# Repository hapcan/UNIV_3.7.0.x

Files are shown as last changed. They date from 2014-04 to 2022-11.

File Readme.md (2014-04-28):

UNIV 3.7.0.x
============

BlIND CONTROLLER - 3 channel for AC motors 230V 200VA for DIN rail

Device webpage: http://hapcan.com/devices/universal/univ_3/univ_3-7-0-x/

Hardware created in Eagle PCB Software http://www.cadsoftusa.com/

Firmware created in Microchip MPLAB http://www.microchip.com/mplabide/ in assembly language

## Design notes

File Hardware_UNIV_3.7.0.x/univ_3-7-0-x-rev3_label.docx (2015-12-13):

BLIND CONTROLLER

3 CHANNEL for AC MOTORS
UN = 230V AC | | SMAX = 200VA /channel
TYPE | UNIV 3.7.0.x
S/N | 00000678h
BUS BUS | hapcan.com

STEROWNIK ROLET

3 KANAŁOWY DLA SILNIKÓW AC
UN = 230V AC | | SMAX = 200VA /kanał
TYP | UNIV 3.7.0.x
S/N | 00000678h
BUS BUS | hapcan.com

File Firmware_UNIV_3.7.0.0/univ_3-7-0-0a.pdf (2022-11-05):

# BLIND CONTROLLER FIRMWARE

# UNIV 3.7.0.0

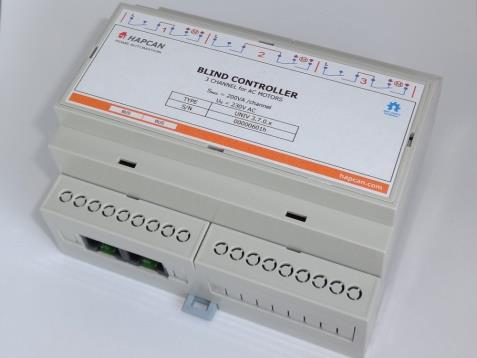
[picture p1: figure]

© 2014 hapcan.com | univ_3-7-0-0a.pdf - page 1 / 5

### 1. Features

- 3 channel blind controller firmware.
- 6 control instructions roletami (START, STOP, UP, DOWN, UP/STOP, DOWN/STOP) makes possible to drive blind with one two or three buttons.
- It estimates position of the blind by the running time.
- 3 timers (1 for each channel) 1s-24h for instruction execution delay.

### - 3 timers (1 for each channel) 1s-256s defining maximum motor running

time.

### - 3 blocking instructions - Allows defining up to 128 CAN messages which can indirectly control the module - Uptime counter - Health check monitor - Transmit (42 messages) and receive (42 messages) FIFO buffers

### 2. Compatibility

### - Firmware for UNIV 3.7.0.x module - Firmware can be uploaded into processor with bootloader version 3.1 or

compatible.

### 3. Firmware version

UNIV | 3 | . | 7 | . | 0 | . | 0

### firmware version application version (blind controller for AC motors) application type (blind controller) processor version universal processor

### 4. Communication Frames (messages)

### 4.1. Blind Controller Frame

The module sends message to the bus, when motors starts running or stops.

Table 1. BLIND CONTROLLER frame (0x307).
Frame type | Flags | Module | Group | D0 | D1 | D2 | D3 | D4 | D5 | D6 | D7
0x307 | 3 | 2 | 1 | 0 | Node Nr | Group Nr | 0xFF | 0xFF | CHANNEL | STATUS | MOVE | INSTR1 | INSTR2 | TIMER
0x307 | – universal module frame, blind controller application
3 | - | - not used flag, read as “0”
2 | - | - not used flag, read as “0”
1 | - | - not used flag, read as “0”
0 | RE | - response flag. Flag is equal “1” if node was requested. If flag is equal „0” it means that status of output has just changed.
Node Nr | - node number on the network
Group Nr | - group number of the node on the network
CHANNEL | - blind number
STATUS | - estimated blind status (0x00-0xFF): 0x00 – blind open, 0xFF – blind closed
MOVE | - defines movement: 0x00 – blind stopped, 0x01 – going down, 0x02 – going up
INSTR1 | - instruction that is waiting for execution, or 0xFF if none instruction
INSTR2 | - second byte of instruction that is waiting for execution, or 0xFF
TIMER | - delay value of waiting instruction, or 0x00 if none waiting

## UNIV 3.7.0.0

### 4.2. Status request

Status of module can be checked by sending from computer STATUS REQUEST frame (0x109) (Table 2).

Table 2. STATUS REQUEST frame (0x109).
Frame type | Flags | Module | Group | D0 | D1 | D2 | D3 | D4 | D5 | D6 | D7
0x109 | 0x0 | COMP ID1 | COMP ID2 | 0xXX | 0xXX | Node Nr | Group Nr | 0xXX | 0xXX | 0xXX | 0xXX
0x1090 | – STATUS REQUEST frame
COMP ID1 | - computer identifier (must be unique on the network)
COMP ID2 | - computer identifier (must be unique on the network)
Node Nr | - node number of requested module
Group Nr | - group number of requested module
0xXX | - inessential data

As response the module will send status frames (Table 3). Meaning of bytes is the same as in Table 1.

Table 3. Response to STATUS REQUEST.
Frame type | Flags | Module | Group | D0 | D1 | D2 | D3 | D4 | D5 | D6 | D7
0x307 | 0x1 | Node Nr | Group Nr | 0xFF | 0xFF | 0x01 | STATUS | MOVE | INSTR1 | 0x01 | TIMER1
Frame type | Flags | Module | Group | D0 | D1 | D2 | D3 | D4 | D5 | D6 | D7
0x307 | 0x1 | Node Nr | Group Nr | 0xFF | 0xFF | 0x02 | STATUS | MOVE | INSTR1 | 0x02 | TIMER2
Frame type | Flags | Module | Group | D0 | D1 | D2 | D3 | D4 | D5 | D6 | D7
0x307 | 0x1 | Node Nr | Group Nr | 0xFF | 0xFF | 0x03 | STATUS | MOVE | INSTR1 | 0x04 | TIMER3

### 4.3. Uptime request

Table 4. UPTIME REQUEST (0x113).
Frame type | Flags | Module | Group | D0 | D1 | D2 | D3 | D4 | D5 | D6 | D7
0x113 | 0x0 | COMP ID1 | COMP ID2 | 0xXX | 0xXX | Node Nr | Group Nr | 0xXX | 0xXX | 0xXX | 0xXX
0x1130 | – UPTIME REQUEST frame
COMP ID1 | - computer identifier (must be unique on the network)
COMP ID2 | - computer identifier (must be unique on the network)
Node Nr | - node number of requested module
Group Nr | - group number of requested module
0xXX | - inessential data

Table 5. Response to UPTIME REQUEST (0x113).
Frame type | Flags | Module | Group | D0 | D1 | D2 | D3 | D4 | D5 | D6 | D7
0x113 | 0x1 | Node Nr | Group Nr | 0xFF | 0xFF | 0xFF | 0xFF | UPTIME3 | UPTIME2 | UPTIME1 | UPTIME0
0x1131 | – Response to UPTIME REQUEST frame
Node Nr | - node number on the network
Group Nr | - group number of the node on the network
UPTIME | - (UPTIME3*256³+UPTIME2*256²+UPTIME1*256¹+UPTIME3*256⁰
) in seconds

### 4.4. Health check request

Table 6. HEALTH CHECK - STATUS REQUEST (0x115).
Frame type | Flags | Module | Group | D0 | D1 | D2 | D3 | D4 | D5 | D6 | D7
0x115 | 0x0 | COMP ID1 | COMP ID2 | 0x01 | 0xXX | Node Nr | Group Nr | 0xXX | 0xXX | 0xXX | 0xXX
0x1150 | – HEALTH CHECK REQUEST frame
COMP ID1 | - computer identifier (must be unique on the network)
COMP ID2 | - computer identifier (must be unique on the network)
0x01 | - status request
Node Nr | - node number of requested module
Group Nr | - group number of requested module
0xXX | - inessential data

As response the module will send two frames (Table 7).

Table 7. Response to HEALTH CHECK - STATUS REQUEST (0x115).
Frame type | Flags | Module | Group | D0 | D1 | D2 | D3 | D4 | D5 | D6 | D7
0x115 | 0x1 | Node Nr | Group Nr | 0x01 | RXCNT | TXCNT | RXCNTMX | TXCNTMX | CANINTCNT | RXERRCNT | TXERRCNT
0x1151 | – Response to HEALTH CHECK REQUEST frame
Node Nr | - node number on the network
Group Nr | - group number of the node on the network
0x01 | - frame 1 (current values)
RXCNT | - current level of receive FIFO buffer
TXCNT | - current level of transmit FIFO buffer
RXCNTMX | - maximum level of receive FIFO buffer since power up
TXCNTMX | - maximum level of transmit FIFO buffer since power up
CANINTCNT | - number of CAN interface restarts since power up
RXERRCNT | - current receive errors register
TXERRCNT | - current transmit errors register
Frame type | Flags | Module | Group | D0 | D1 | D2 | D3 | D4 | D5 | D6 | D7
0x115 | 0x1 | Node Nr | Group Nr | 0x02 | 0xFF | 0xFF | RXCNTMXE | TXCNTMXE | CANINTCNTE | RXERRCNTE | TXERRCNTE
0x1151 | – Response to HEALTH CHECK REQUEST frame
Node Nr | - node number on the network
Group Nr | - group number of the node on the network
0x02 | - frame 2 (maximum values saved in eeprom memory)
RXCNTMXE | - maximum ever level of receive FIFO buffer
TXCNTMXE | - maximum ever level of transmit FIFO buffer
CANINTCNTE | - maximum ever number of CAN interface restarts
RXERRCNTE | - maximum ever receive errors
TXERRCNTE | - maximum ever transmit errors

To clear maximum values saved in eeprom memory the frame shown in Table 8 must be sent. There is no response to this message.

Table 8. HEALTH CHECK - CLEAR REQUEST (0x115).
Frame type | Flags | Module | Group | D0 | D1 | D2 | D3 | D4 | D5 | D6 | D7
0x115 | 0x0 | COMP ID1 | COMP ID2 | 0x02 | 0xXX | Node Nr | Group Nr | 0xXX | 0xXX | 0xXX | 0xXX
0x1150 | – HEALTH CHECK REQUEST frame
COMP ID1 | - computer identifier (must be unique on the network)
COMP ID2 | - computer identifier (must be unique on the network)
0x02 | - clear request
Node Nr | - node number of requested module
Group Nr | - group number of requested module
0xXX | - inessential data

### 5. Module control

The module can be controlled directly from PC, or indirectly by other modules. In both situation all instructions in the table below can be used. Blocking instructions can’t be used in direct control.

### 5.1. Control instruction

The Table 9 shows instructions, which can be executed by the module.

### Table 9. Module control instructions

Instruction | Instruction Codding | Note | Control
INSTR1 | INSTR2 | INSTR3 | INSTR4 | INSTR5 | INSTR6 | INSTR7 | INSTR8
STOP | 0x00 | CHANNEL | TIMER | 0xXX | 0xXX | 0xXX | 0xXX | 0xXX | It stops chosen blinds. Executing of the next instruction will be possible only after 1 second. | √ | √
UP/STOP | 0x01 | CHANNEL | TIMER | 0xXX | 0xXX | 0xXX | 0xXX | 0xXX | It runs blind up, if it was stopped. It stops blind, if it was running.
DOWN/STOP | 0x02 | CHANNEL | TIMER | 0xXX | 0xXX | 0xXX | 0xXX | 0xXX | It runs blind down, if it was stopped. It stops blind, if it was running.
UP | 0x03 | CHANNEL | TIMER | 0xXX | 0xXX | 0xXX | 0xXX | 0xXX | It runs blind up, if was stopped. It stops, and after 1s runs blind up, if was running down.
DOWN | 0x04 | CHANNEL | TIMER | 0xXX | 0xXX | 0xXX | 0xXX | 0xXX | It runs blind down, if was stopped. It stops, and after 1s runs blind down, if was running up.
START | 0x05 | CHANNEL | TIMER | 0xXX | 0xXX | 0xXX | 0xXX | 0xXX | It stops blind if was running. It runs blind opposite way to last running, if blind was stopped.

Direct

Indirect

0xXX – inessential data

CHANNEL | Note
0x01 | - <00000001> - only blind 1
0x02 | - <00000010> - only blind 2
0x03 | - <00000011> - blind 1 & 2
0x04 | - <00000100> - only blind 3
…
0x07 | - <00000111> - blind 1, 2, 3
bit <0> - blind 1
bit <1> - blind 2
bit <2> - blind 3
TIMER | Note
0x00 | - instruction will be executed immediately
0x01 | - instruction will be executed with 1s delay
…
0xFF | - instruction will be executed with 24h delay
ENABLE BOX | 0xDD | BoxX | BoxY | 0xXX | 0xXX | 0xXX | 0xXX | 0xXX | It enables chosen boxes – these boxes will be compared with next received message from the bus. | √
DISABLE BOX | 0xDE | BoxX | BoxY | 0xXX | 0xXX | 0xXX | 0xXX | 0xXX | It disables chosen boxes – these boxes will be passed when next message arrives from the bus. | √
TOGGLE BOX | 0xDF | BoxX | BoxY | 0xXX | 0xXX | 0xXX | 0xXX | 0xXX | It toggles boxes – enables when they are disabled and vice versa | √

0xXX – inessential data

BoxX | Note
0x00 | - from Box 1
0x01 | - from Box 2
…
0x7F | - from Box 128
BoxY | Note
0x00 | + 0 -(and not anyone else)
0x01 | + 1 -( and 1 following)
…
0x7F | +127 -( and 127 following)

### 5.2. Timer

Each relay has its own timer which can delay execution of the instruction. Delay can be chosen between 1s-24h set in TIMER register. Drawing below shows delay dependence of TIMER register.

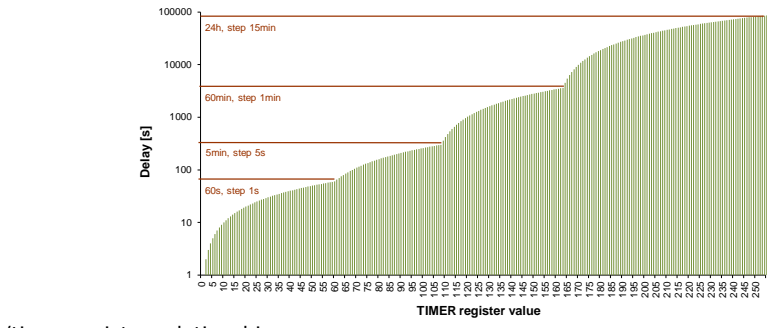
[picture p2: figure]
Delay [s]; TIMER register value; 60s, step 1s; 5min, step 5s; 60min, step 1min; 24h, step 15min

### Figure 1. Delay/timer register relationship

### 5.3. Direct control

It is possible to control module by sending DIRECT CONTROL message. The message contains instruction, which will be executed by the module. The module can be also controlled from HAPCAN Programmer.

Table 10. DIRECT CONTROL frame (0x10A).
Frame type | Flags | Module | Group | D0 | D1 | D2 | D3 | D4 | D5 | D6 | D7
0x10A | 0x0 | COMP ID1 | COMP ID2 | INSTR1 | INSTR2 | Node Nr | Group Nr | INSTR3 | INSTR4 | INSTR5 | INSTR6
0x10A | – DIRECT CONTROL frame
COMP ID1 | - computer identifier (must be unique on the network)
COMP ID2 | - computer identifier (must be unique on the network)
Node Nr | - node number of requested module
Group Nr | - group number of requested module
INSTR1-6 | - instruction to be executed (byte1)

### 5.4. Indirect control

Indirect control means that module will react to messages sent by other modules on the network. It depends on configuration programmed into the module boxes (memory cells).
This firmware has feature to set simple conditions of executing instruction. To do so, you can use blocking instruction (0xDD – 0xDF) shown in Table 9.

### 6. Configuration Parameters that can be configured with this firmware:

- Module identifier (module number and group number);
- Module description (16 chars);
- Blind names;
- Blind running times;
- Text notes;
- Linking device with other modules (indirect control of module). Configuration process can be done using HAPCAN Programmer.

### 6.1. Module identifier

Every module on the network must have unique identifier. The identifier is made of two bytes, module number (1 byte) and group number (1 byte). Identifier of the Ethernet Interface can be changed in HAPCAN Programmer in software settings.

### 6.2. Module description

Every module can have 16 char description, which makes easier for user (programmer) to distinguish nodes.

### 6.3. Relay Names

Each relay can be named with 32 chars.

### 6.4. Blind running time

For every channel (motor) the running time can be chosen. It is the time needed for complete closing of the blind from complete open position, or complete opening from complete shutting, whichever is longer. Basing on this time the module will estimate position of the blind.

6.5. Text notes.
Up to 1024 characters can be written into processor’s memory.

### 6.6. Linking devices

The module has 128 memory cells (boxes). Each box can contain information about message sent by other node, and instruction which will be executed when that message is received.

### 7. License

HAPCAN Home Automation Project firmware, Copyright (C) 2014 hapcan.com

This program is free firmware: you can redistribute it and/or modify it under the terms of the GNU General Public License as published by the Free Software Foundation, either version 3 of the License, or (at your option) any later version.

This firmware is distributed in the hope that it will be useful, but WITHOUT ANY WARRANTY; without even the implied warranty of MERCHANTABILITY or FITNESS FOR A PARTICULAR PURPOSE. See the GNU General Public License for more details.

You should have received a copy of the GNU General Public License along with this firmware. If not, see http://www.gnu.org/licenses/gpl-3.0.html.

### 8. Document version

File | Note | Date
univ_3-7-0-0a.pdf | Original version | April 2014

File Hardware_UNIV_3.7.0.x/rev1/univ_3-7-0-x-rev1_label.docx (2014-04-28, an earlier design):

BLIND CONTROLLER

3 CHANNEL for AC MOTORS

SMAX = 200VA /channel

UN = 230V AC
TYPE | UNIV 3.7.0.x
S/N | 00000601h
BUS BUS | hapcan.com

STEROWNIK ROLET

3 KANAŁOWY DLA SILNIKÓW AC

SMAX = 200VA /kanał

UN = 230V AC
TYP | UNIV 3.7.0.x
S/N | 00000601h
BUS BUS | hapcan.com

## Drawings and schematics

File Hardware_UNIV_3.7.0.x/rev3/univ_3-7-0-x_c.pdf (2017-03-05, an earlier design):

## BLIND CONTROLLER FOR AC MOTORS

# UNIV 3.7.0.x

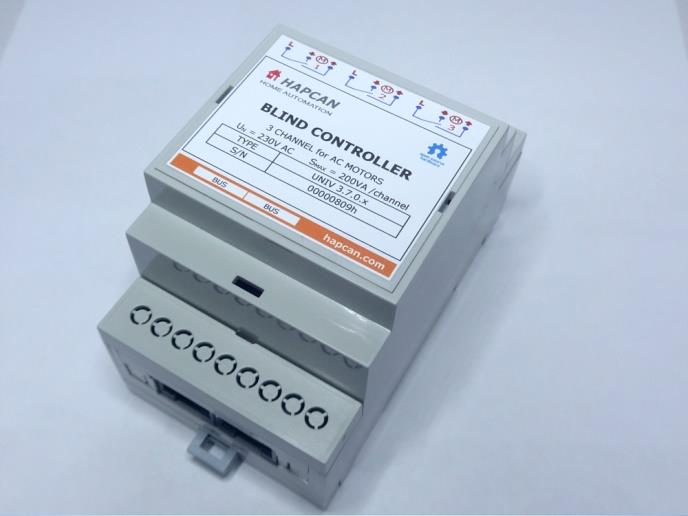
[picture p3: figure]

© 2015 hapcan.com | univ_3-7-0-x_c.pdf - page 1 / 6

### 1. Features

- 3 channel blind controller for blinds with AC motors 230V 200VA.
- The blind must have built-in limit switches and motor overload protection
- Motor running direction is defined by driven winding (forward or reverse)
- The module makes impossible to drive two motor windings at the same time.
- Motor nominal voltage 230V
- Maximum motor power 200VA
- Bus voltage 16-24V
- Maximum current consumption from the bus 83mA@16V
- For DIN rail mounting.
- Dimensions 90x58x53 mm (3 mod)
- Operating of module depends on firmware uploaded into it.
- Schematic and PCB design can be downloaded from hapcan.com site

### 2. Application version

UNIV | 3 | . | 7 | . | 0 | . | x
firmware version
application version (blind controller for AC motors) application type (blind controller)
processor version
universal processor

### 3. Technical data

Bus side
Parameter | Symbol | Value | Unit
Power supply voltage | US | 16-24 | V DC
Current consumption | IS | 8@16V 6@24V | mA
Maximum current consumption (when all relays are on – 3 blinds go up) | ISMAX | 83@16V 56@24V | mA
Bus connector type | 2x RJ45

Relay side
Parameter | Symbol | Value | Unit
Coil voltage | UCOIL | 12 | V DC
Coil resistance | RCOIL | 840 | Ω
Nominal contacts current | IN | 6 | A
Maximum inrush current | IINRUSH | 10 | A
Nominal motor voltage. | UN | 230 | V AC
Maximum load per channel. | SMAX | 200 | VA
Relay connector type | Terminal Blocks (solid wire 4mm² , stranded 2,5mm² )

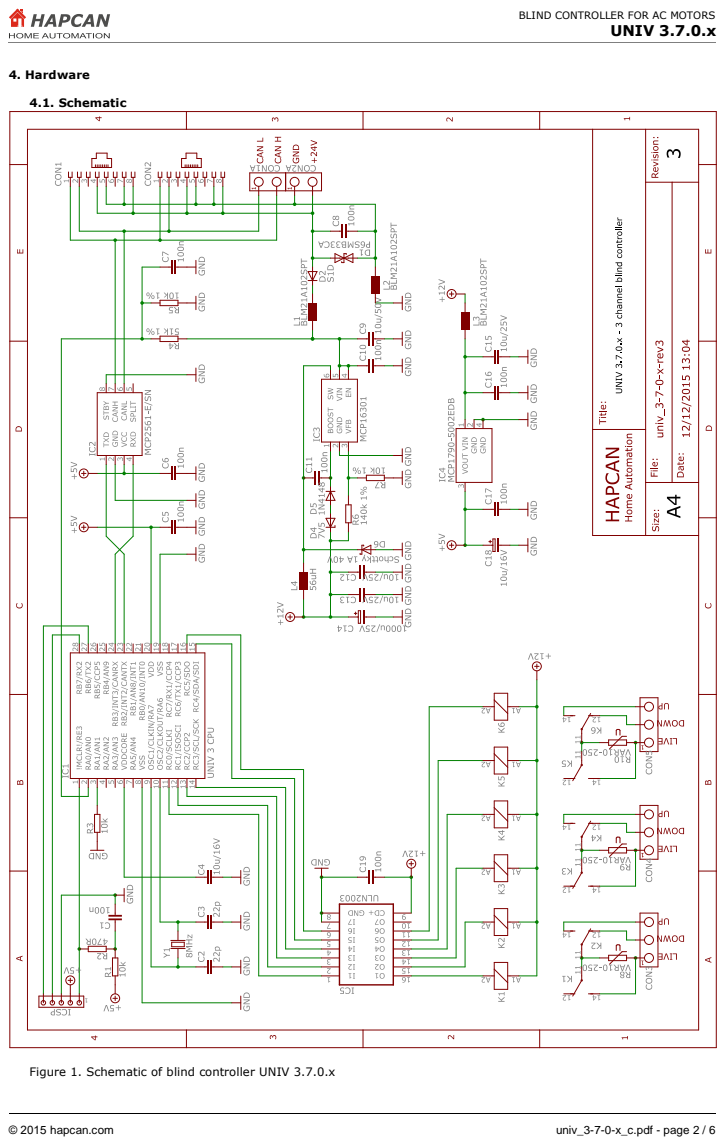
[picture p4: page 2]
4. Hardware; 4.1. Schematic

Figure 1. Schematic of blind controller UNIV 3.7.0.x

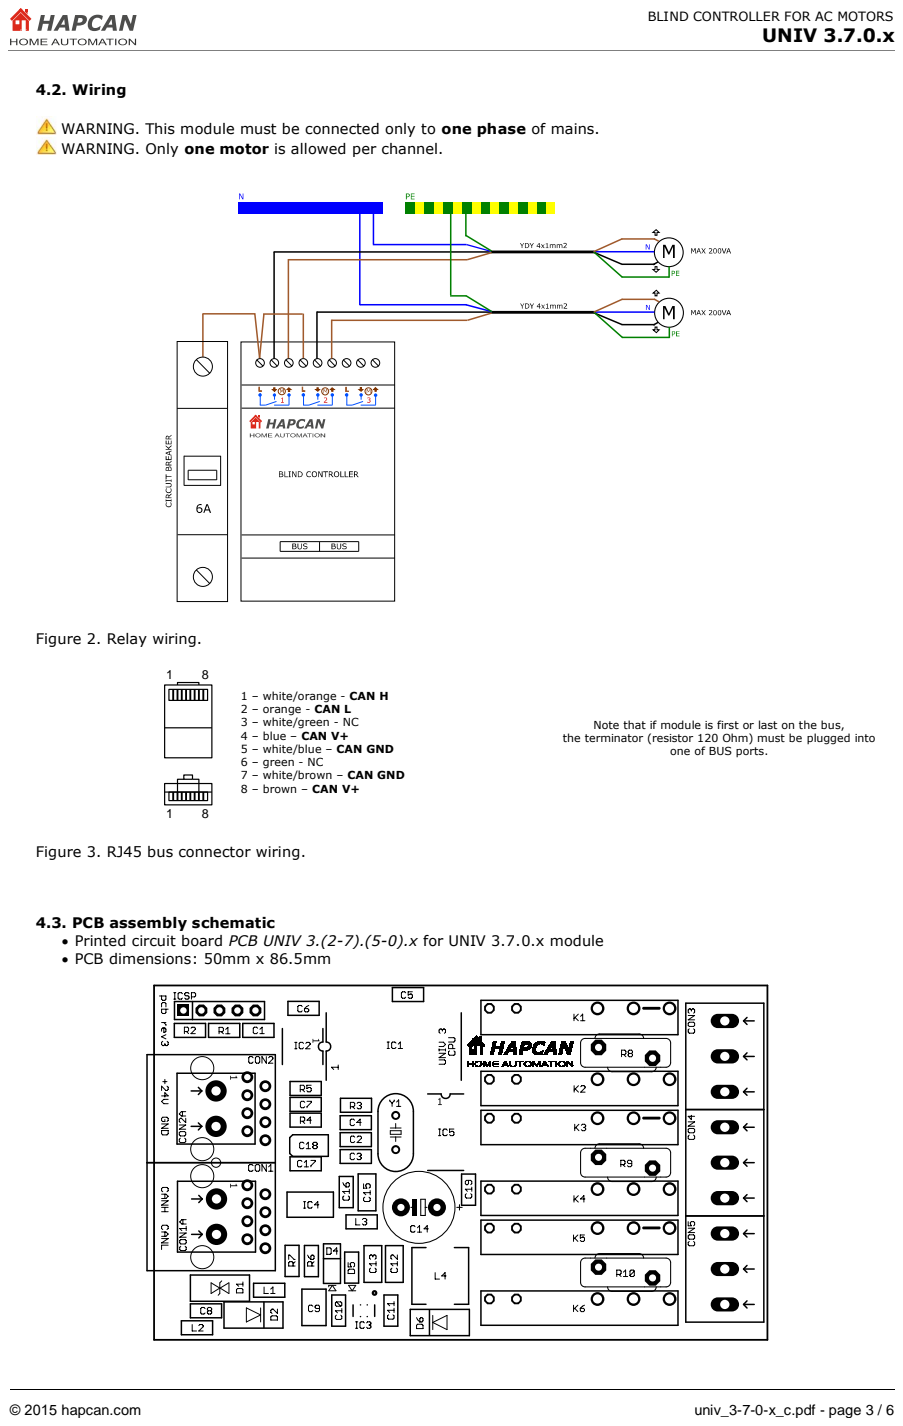
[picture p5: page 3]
4.2. Wiring

WARNING. This module must be connected only to one phase of mains.
WARNING. Only one motor is allowed per channel.

Figure 2. Relay wiring.

1 – white/orange - CAN H
2 – orange - CAN L
3 – white/green - NC
4 – blue – CAN V+
5 – white/blue – CAN GND
6 – green - NC
7 – white/brown – CAN GND
8 – brown – CAN V+

Note that if module is first or last on the bus,
the terminator (resistor 120 Ohm) must be plugged into

one of BUS ports.

Figure 3. RJ45 bus connector wiring.

4.3. PCB assembly schematic
• Printed circuit board PCB UNIV 3.(2-7).(5-0).x for UNIV 3.7.0.x module
• PCB dimensions: 50mm x 86.5mm

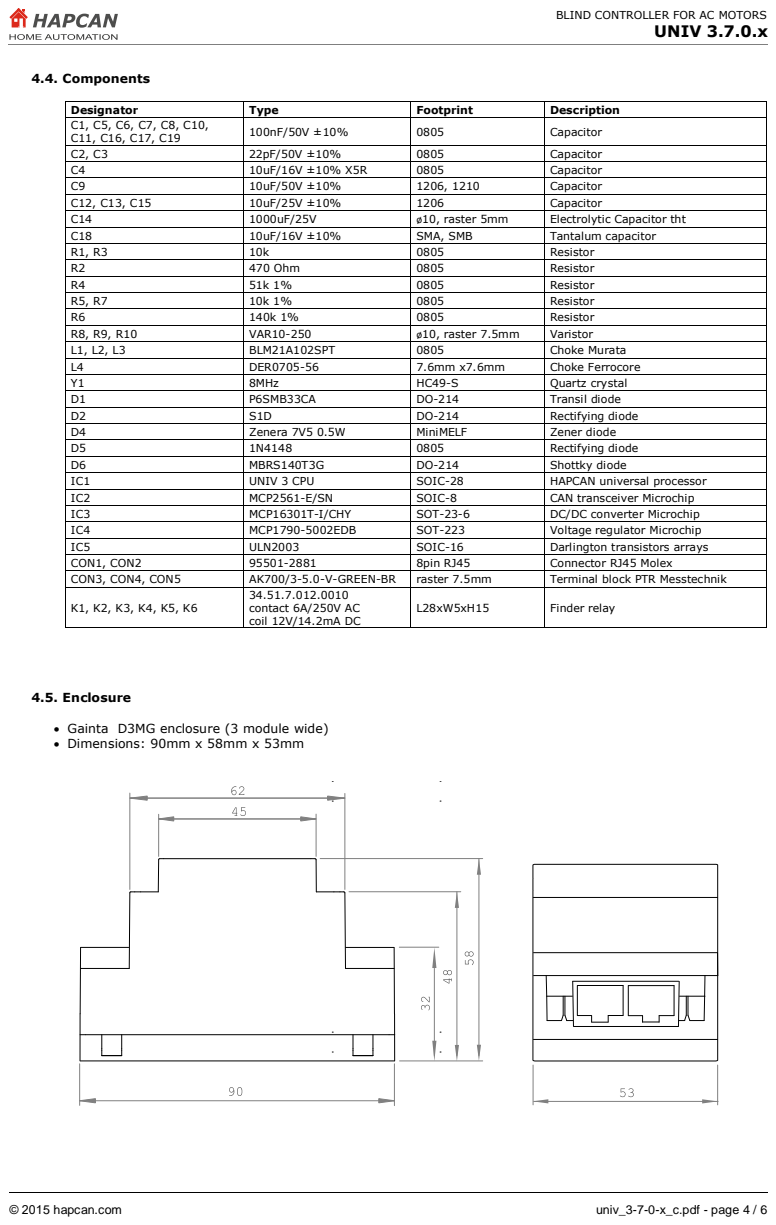
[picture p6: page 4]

Designator | Type | Footprint | Description
C1, C5, C6, C7, C8, C10, C11, C16, C17, C19 | 100nF/50V ±10% | 0805 | Capacitor

C2, C3 | 22pF/50V ±10% | 0805 | Capacitor
C4 | 10uF/16V ±10% X5R | 0805 | Capacitor
C9 | 10uF/50V ±10% | 1206, 1210 | Capacitor
C12, C13, C15 | 10uF/25V ±10% | 1206 | Capacitor
C14 | 1000uF/25V | ø10, raster 5mm | Electrolytic Capacitor tht
C18 | 10uF/16V ±10% | SMA, SMB | Tantalum capacitor
R1, R3 | 10k | 0805 | Resistor
R2 | 470 Ohm | 0805 | Resistor
R4 | 51k 1% | 0805 | Resistor
R5, R7 | 10k 1% | 0805 | Resistor
R6 | 140k 1% | 0805 | Resistor
R8, R9, R10 | VAR10-250 | ø10, raster 7.5mm | Varistor
L1, L2, L3 | BLM21A102SPT | 0805 | Choke Murata
L4 | DER0705-56 | 7.6mm x7.6mm | Choke Ferrocore
Y1 | 8MHz | HC49-S | Quartz crystal
D1 | P6SMB33CA | DO-214 | Transil diode
D2 | S1D | DO-214 | Rectifying diode
D4 | Zenera 7V5 0.5W | MiniMELF | Zener diode
D5 | 1N4148 | 0805 | Rectifying diode
D6 | MBRS140T3G | DO-214 | Shottky diode
IC1 | UNIV 3 CPU | SOIC-28 | HAPCAN universal processor
IC2 | MCP2561-E/SN | SOIC-8 | CAN transceiver Microchip
IC3 | MCP16301T-I/CHY | SOT-23-6 | DC/DC converter Microchip
IC4 | MCP1790-5002EDB | SOT-223 | Voltage regulator Microchip
IC5 | ULN2003 | SOIC-16 | Darlington transistors arrays
CON1, CON2 | 95501-2881 | 8pin RJ45 | Connector RJ45 Molex
CON3, CON4, CON5 | AK700/3-5.0-V-GREEN-BR | raster 7.5mm | Terminal block PTR Messtechnik
K1, K2, K3, K4, K5, K6 | 34.51.7.012.0010 contact 6A/250V AC coil 12V/14.2mA DC | L28xW5xH15 | Finder relay

• Gainta D3MG enclosure (3 module wide)
• Dimensions: 90mm x 58mm x 53mm

### 4.6. Mechanical processing

Striped parts must be removed.

BODY | TERMINAL GUARDS

1x

1x

### 4.7. Label

Editable label version is available at hapcan.com website.

BLIND CONTROLLER

3 CHANNEL for AC MOTORS
UN = 230V AC | SMAX = 200VA /channel
TYPE | UNIV 3.7.0.x
S/N | 00000678h
BUS | BUS | hapcan.com

### 5. Commissioning
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

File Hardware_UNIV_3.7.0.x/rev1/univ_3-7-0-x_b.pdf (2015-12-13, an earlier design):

## BLIND CONTROLLER FOR AC MOTORS

# UNIV 3.7.0.x

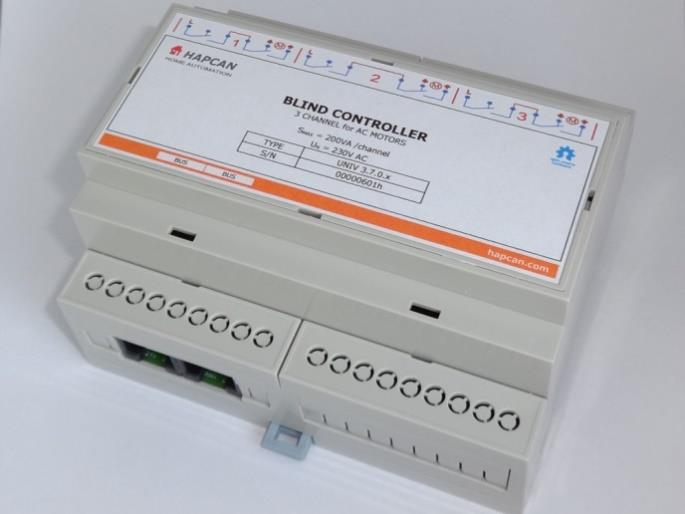
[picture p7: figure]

© 2014 hapcan.com | univ_3-7-0-x_b.pdf - page 1 / 6

### 1. Features

- 3 channel blind controller for blinds with AC motors 230V 200VA.
- The blind must have built-in limit switches and motor overload protection
- Motor running direction is defined by driven winding (forward or reverse)
- The way the module must be connected to motor, makes impossible to drive two windings at the same time.
- Motor nominal voltage 230V
- Maximum motor power 200VA
- Bus voltage 16-24V
- Maximum current consumption from the bus 120mA
- For DIN rail mounting.
- Dimensions 90x106x53 mm (6 mod)
- Operating of module depends on firmware uploaded into it.
- Schematic and PCB design can be downloaded from hapcan.com site

### 2. Application version

UNIV | 3 | . | 7 | . | 0 | . | x
firmware version
application version (blind controller for AC motors) application type (blind controller)
processor version
universal processor

### 3. Technical data

Bus side
Parameter | Symbol | Value | Unit
Power supply voltage | US | 16-24V | V
Current consumption | IS | 12 | mA
Maximum current consumption (when all relays are on) | ISMAX | 120 | mA
Bus connector type | 2x RJ45

Relay side
Parameter | Symbol | Value | Unit
Nominal contacts current | IN | 5 | A
Maximum inrush current | IINRUSH | 5 | A
Nominal motor voltage. | UN | 230 | V AC
Maximum load per channel. | SMAX | 200 | VA
Relay connector type | Terminal Blocks (solid wire 4mm² , stranded 2,5mm² )

## UNIV 3.7.0.x

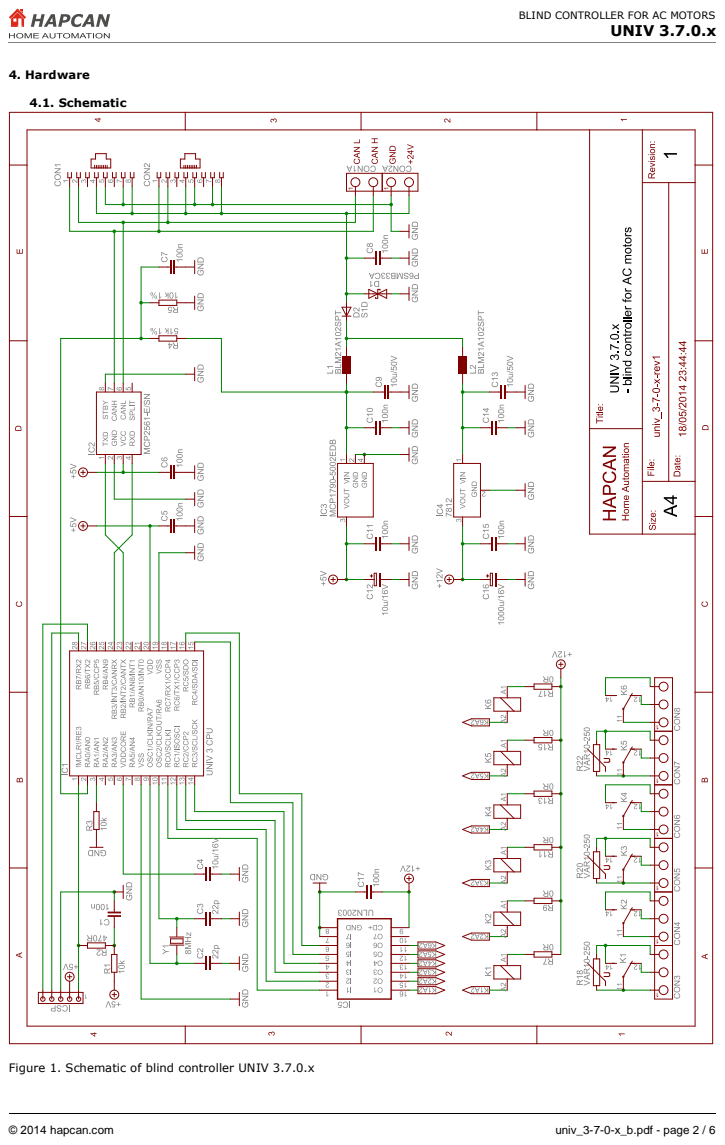
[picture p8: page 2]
4. Hardware; 4.1. Schematic

Figure 1. Schematic of blind controller UNIV 3.7.0.x

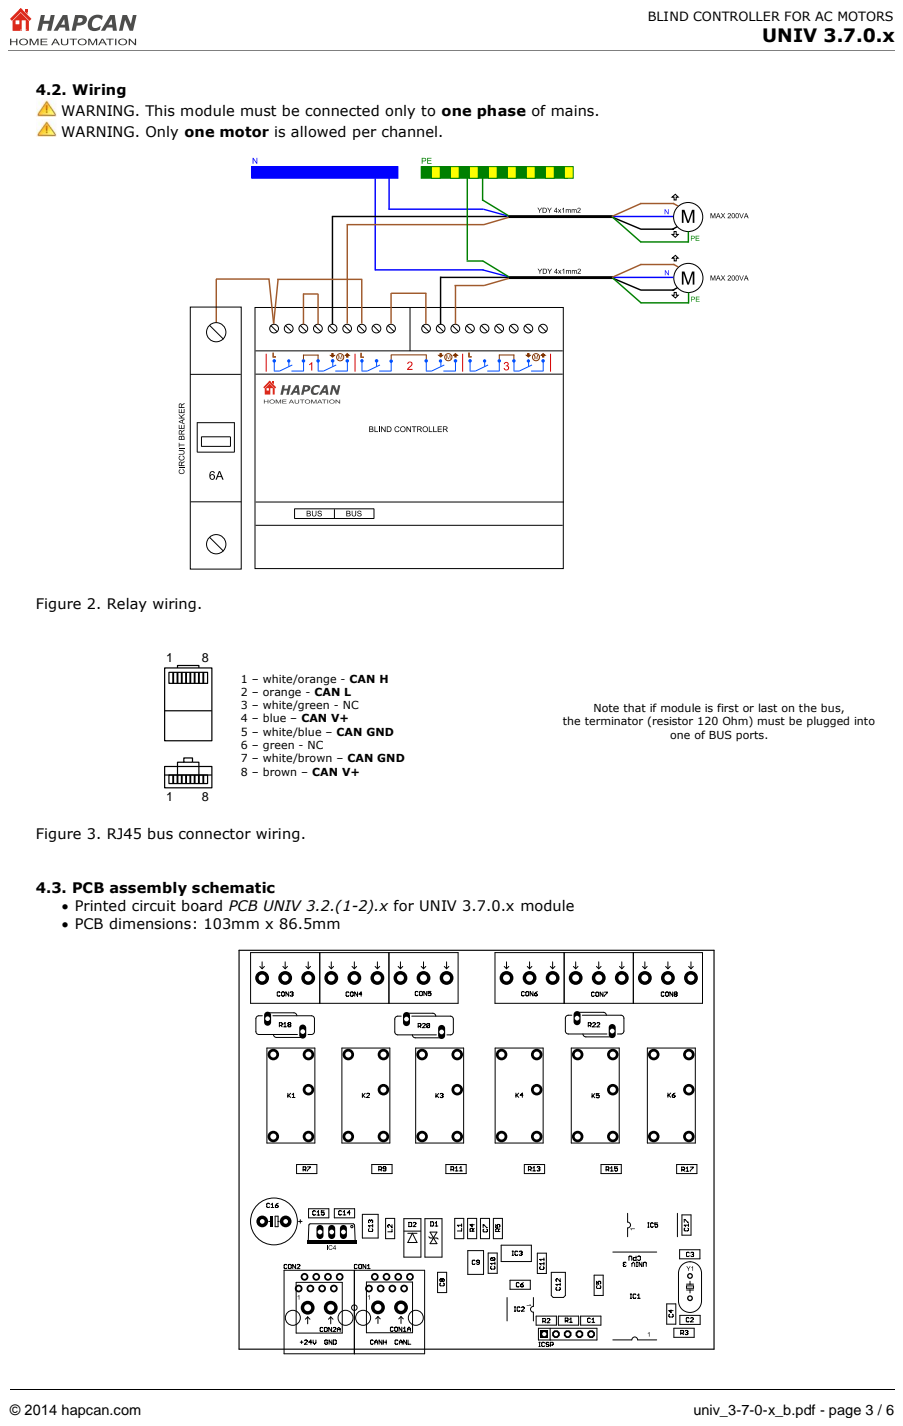
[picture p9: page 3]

4.2. Wiring
WARNING. This module must be connected only to one phase of mains.
WARNING. Only one motor is allowed per channel.

Figure 2. Relay wiring.

1 – white/orange - CAN H
2 – orange - CAN L
3 – white/green - NC
4 – blue – CAN V+
5 – white/blue – CAN GND
6 – green - NC
7 – white/brown – CAN GND
8 – brown – CAN V+

Note that if module is first or last on the bus,
the terminator (resistor 120 Ohm) must be plugged into

one of BUS ports.

Figure 3. RJ45 bus connector wiring.

4.3. PCB assembly schematic
• Printed circuit board PCB UNIV 3.2.(1-2).x for UNIV 3.7.0.x module
• PCB dimensions: 103mm x 86.5mm

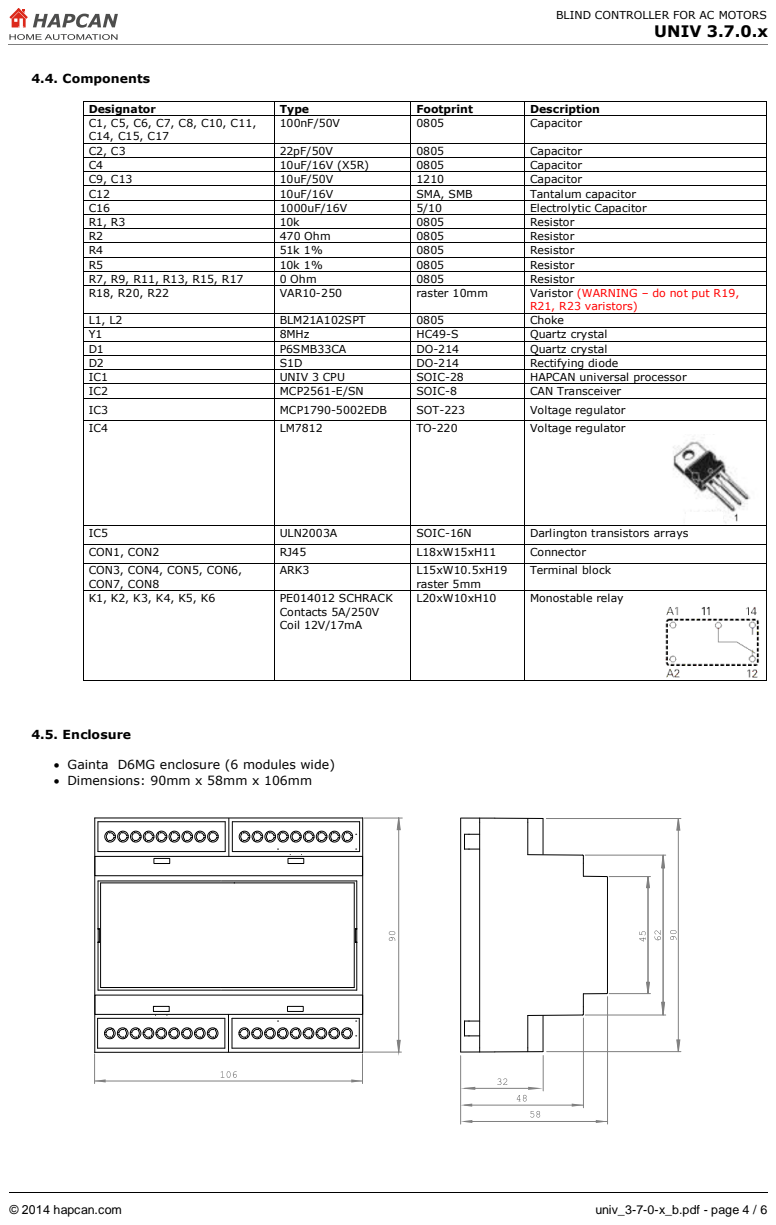
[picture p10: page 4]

Designator | Type | Footprint | Description
C1, C5, C6, C7, C8, C10, C11, C14, C15, C17 | 100nF/50V | 0805 | Capacitor

C2, C3 | 22pF/50V | 0805 | Capacitor
C4 | 10uF/16V (X5R) | 0805 | Capacitor
C9, C13 | 10uF/50V | 1210 | Capacitor
C12 | 10uF/16V | SMA, SMB | Tantalum capacitor
C16 | 1000uF/16V | 5/10 | Electrolytic Capacitor
R1, R3 | 10k | 0805 | Resistor
R2 | 470 Ohm | 0805 | Resistor
R4 | 51k 1% | 0805 | Resistor
R5 | 10k 1% | 0805 | Resistor
R7, R9, R11, R13, R15, R17 | 0 Ohm | 0805 | Resistor
R18, R20, R22 | VAR10-250 | raster 10mm | Varistor (WARNING – do not put R19, R21, R23 varistors)

L1, L2 | BLM21A102SPT | 0805 | Choke
Y1 | 8MHz | HC49-S | Quartz crystal
D1 | P6SMB33CA | DO-214 | Quartz crystal
D2 | S1D | DO-214 | Rectifying diode
IC1 | UNIV 3 CPU | SOIC-28 | HAPCAN universal processor
IC2 | MCP2561-E/SN | SOIC-8 | CAN Transceiver
IC3 | MCP1790-5002EDB | SOT-223 | Voltage regulator
IC4 | LM7812 | TO-220 | Voltage regulator

IC5 | ULN2003A | SOIC-16N | Darlington transistors arrays
CON1, CON2 | RJ45 | L18xW15xH11 | Connector
CON3, CON4, CON5, CON6, CON7, CON8 | ARK3 | L15xW10.5xH19 raster 5mm | Terminal block

K1, K2, K3, K4, K5, K6 | PE014012 SCHRACK Contacts 5A/250V Coil 12V/17mA | L20xW10xH10 | Monostable relay

• Gainta D6MG enclosure (6 modules wide)
• Dimensions: 90mm x 58mm x 106mm

### 4.6. Mechanical processing

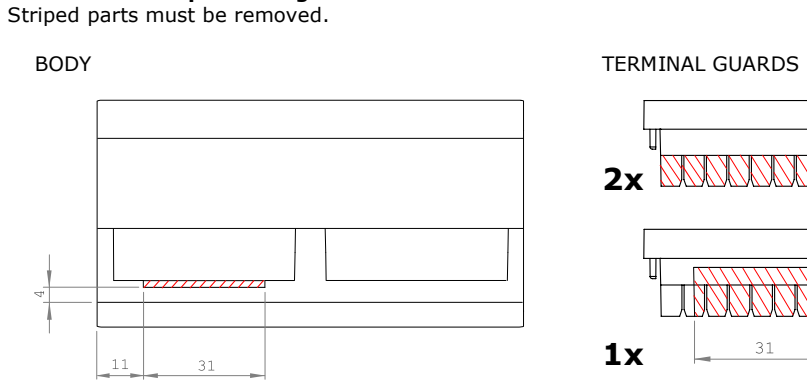
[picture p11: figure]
Striped parts must be removed.; BODY; TERMINAL GUARDS

### 4.7. Label

Editable label version is available at hapcan.com website.

### 5. Commissioning

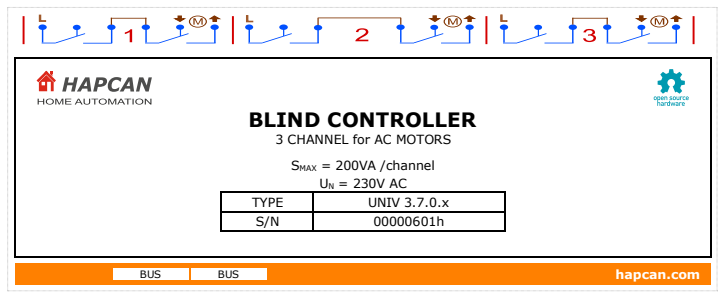
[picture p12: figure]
BLIND CONTROLLER; 3 CHANNEL for AC MOTORS; SMAX = 200VA /channel UN = 230V AC; TYPE; UNIV 3.7.0.x; BUS; hapcan.com

### 5.1. CPU voltage measurement

After verifying the correctness and quality of the soldering, the bus voltage should be connected while measuring the processor voltage. To do this, connect a voltmeter to pins 2 and 3 of the ICSP connector. Processor supply voltage should be about 5V.

Figure 4. CPU voltage measurement
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

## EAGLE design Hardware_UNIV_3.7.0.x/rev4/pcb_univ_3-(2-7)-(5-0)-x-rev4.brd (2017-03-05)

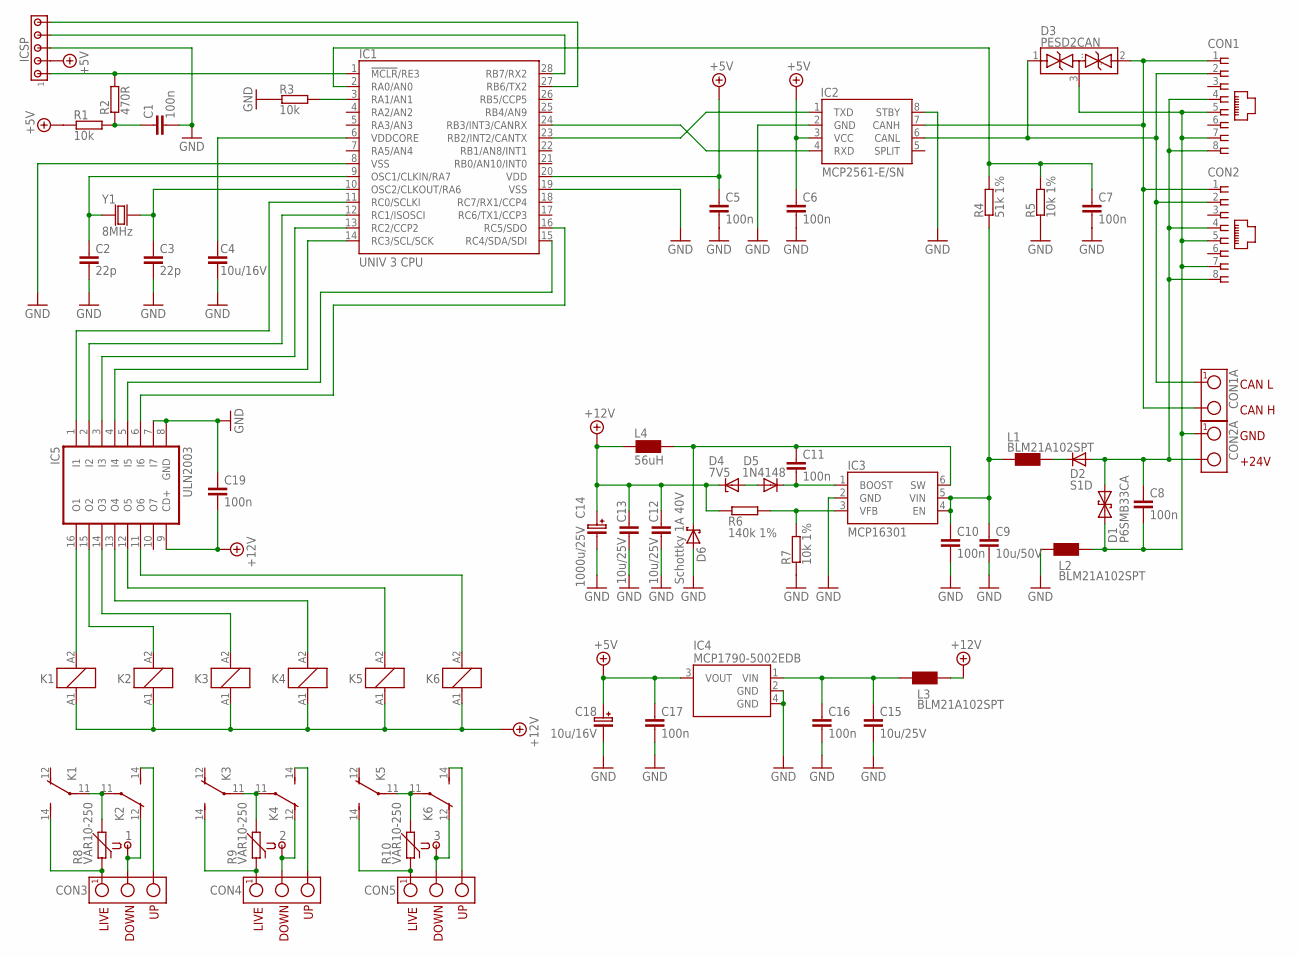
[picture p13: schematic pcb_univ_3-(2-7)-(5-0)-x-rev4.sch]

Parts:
1, 2, 3: HEADER11X0.9; SIP-1
C1, C5, C6, C7, C8, C10, C11, C16, C17, C19: 100n; 0805
C2, C3: 22p; 0805
C4: 10u/16V; 0805
C9: 10u/50V; 1210
C12, C13, C15: 10u/25V; 1206
C14: 1000u/25V; CAP-5X10.5
C18: 10u/16V; SMC_B
CON1, CON2: RJ45-SOCKET; RJ45-PCB-SOCKET
CON1A, CON2A: TERMINAL-2; ARK2-5X10,5MM
CON3, CON4, CON5: TERMINAL-3-5X10.5MM; ARK3-5X10.5MM
D1: P6SMB33CA; DO-214_TRANSIL2
D2: S1D; DO-214
D3: PESD2CAN; SOT-23
D4: 7V5; SOD-80
D5: 1N4148; 0805
D6: Schottky 1A 40V; DO-214
IC1: UNIV 3 CPU; UNIV3CPU
IC2: MCP2561-E/SN; SO-08
IC3: MCP16301; SOT-23-6
IC4: MCP1790-5002EDB; SOT-223
IC5: ULN2003; SO-16
ICSP: HEADER5; SIP-5
K1, K2, K3, K4, K5, K6: RELAY_SNR_SPDTV; RELAY_SNR_SPDT_V
L1, L2, L3: BLM21A102SPT; 0805
L4: 56uH; CHOKE-DER0705
R1, R3: 10k; 0805
R2: 470R; 0805
R4: 51k 1%; 0805
R5, R7: 10k 1%; 0805
R6: 140k 1%; 0805
R8, R9, R10: VAR10-250; VARISTOR1
Y1: 8MHz; CRYSTAL-HC49V

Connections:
+5V: C5.1, C6.1, C17.1, C18.+ (1), IC1.20 (VDD), IC2.3 (VCC), IC4.3 (VOUT), ICSP.2, R1.1
+12V: C12.1, C13.1, C14.+ (1), C19.2, D4.C, IC5.9 (CD+), K1.A1 (1), K2.A1 (1), K3.A1 (1), K4.A1 (1), K5.A1 (1), K6.A1 (1), L3.2, L4.1, R6.1
GND: C1.2, C2.2, C3.2, C4.2, C5.2, C6.2, C7.2, C9.2, C10.2, C12.2, C13.2, C14.- (2), C15.2, C16.2, C17.2, C18.- (2), C19.1, D6.A, IC1.8 (VSS), IC1.19 (VSS), IC2.2 (GND), IC2.8 (STBY), IC3.2 (GND), IC4.2 (GND), IC4.4 (GND), IC5.7 (I7), IC5.8 (GND), ICSP.3, L2.1, R3.1, R5.1, R7.1
unnamed: D2.C, L1.2
unnamed: IC1.24 (RB3/INT3/CANRX), IC2.4 (RXD)
unnamed: IC1.23 (RB2/INT2/CANTX), IC2.1 (TXD)
unnamed: CON1.1, CON1A.2, CON2.1, D3.2 (..), IC2.7 (CANH)
unnamed: C9.1, C10.1, IC3.4 (EN), IC3.5 (VIN), L1.1, R4.1
unnamed: C15.1, C16.1, IC4.1 (VIN), L3.1
unnamed: C1.1, R1.2, R2.1
unnamed: IC1.1 (!MCLR!/RE3), ICSP.1, R2.2
unnamed: C8.1, CON1.4, CON1.8, CON2.4, CON2.8, CON2A.2, D1.C (2), D2.A
unnamed: IC1.28 (RB7/RX2), ICSP.4
unnamed: IC1.12 (RC1/ISOSCI), IC5.2 (I2)
unnamed: IC1.3 (RA1/AN1), R3.2
unnamed: C8.2, CON1.5, CON1.7, CON2.5, CON2.7, CON2A.1, D1.A (1), D3.3 (...), L2.2
unnamed: IC1.27 (RB6/TX2), ICSP.5
unnamed: C3.1, IC1.10 (OSC2/CLKOUT/RA6), Y1.2
unnamed: C7.1, IC1.2 (RA0/AN0), R4.2, R5.2
unnamed: C11.1, D6.C, IC3.6 (SW), L4.2
unnamed: IC1.11 (RC0/SCLKI), IC5.1 (I1)
unnamed: IC1.13 (RC2/CCP2), IC5.3 (I3)
unnamed: IC3.3 (VFB), R6.2, R7.2
unnamed: IC5.16 (O1), K1.A2 (2)
unnamed: IC1.14 (RC3/SCL/SCK), IC5.4 (I4)
unnamed: D4.A, D5.2 (A)
unnamed: IC1.15 (RC4/SDA/SDI), IC5.5 (I5)
unnamed: IC5.15 (O2), K2.A2 (2)
unnamed: IC5.14 (O3), K3.A2 (2)
unnamed: CON1.2, CON1A.1, CON2.2, D3.1 (.), IC2.6 (CANL)
unnamed: IC5.13 (O4), K4.A2 (2)
unnamed: IC5.12 (O5), K5.A2 (2)
unnamed: CON3.1, K1.14 (NO), R8.1
unnamed: IC5.11 (O6), K6.A2 (2)
unnamed: K1.11 (COM), K2.11 (COM), R8.2
unnamed: CON3.3, K2.14 (NO)
unnamed: 1.1, CON3.2, K2.12 (NC)
unnamed: K3.11 (COM), K4.11 (COM), R9.2
unnamed: 2.1, CON4.2, K4.12 (NC)
unnamed: C11.2, D5.1 (C), IC3.1 (BOOST)
unnamed: CON4.3, K4.14 (NO)
unnamed: C2.1, IC1.9 (OSC1/CLKIN/RA7), Y1.1
unnamed: 3.1, CON5.2, K6.12 (NC)
unnamed: CON5.3, K6.14 (NO)
unnamed: IC1.16 (RC5/SDO), IC5.6 (I6)
unnamed: K5.11 (COM), K6.11 (COM), R10.2
unnamed: C4.1, IC1.6 (VDDCORE)
unnamed: CON4.1, K3.14 (NO), R9.1
unnamed: CON5.1, K5.14 (NO), R10.1

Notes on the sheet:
CAN L
CAN H
GND
+24V
DOWN
LIVE

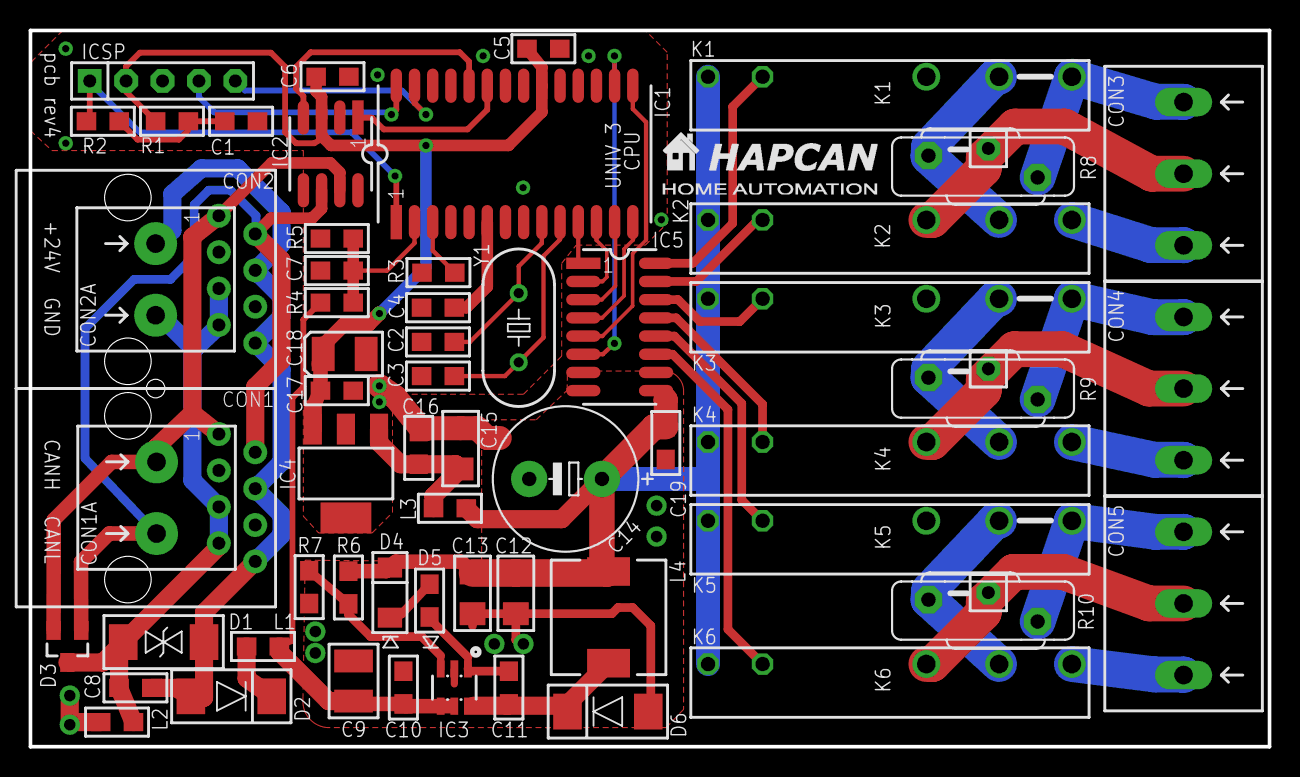
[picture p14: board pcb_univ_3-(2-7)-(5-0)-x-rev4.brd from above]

Board: 2 copper layers, 86.5 x 50.0 mm, 62 parts (0 on the bottom side), 49 nets.

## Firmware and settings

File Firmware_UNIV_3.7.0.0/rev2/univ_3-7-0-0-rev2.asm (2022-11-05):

;==============================================================================
;   MIT License
;
;   Copyright (c) 2022 HAPCAN Home Automation Project (http://hapcan.com)
;
;   Permission is hereby granted, free of charge, to any person obtaining a copy
;   of this software and associated documentation files (the "Software"), to deal
;   in the Software without restriction, including without limitation the rights
;   to use, copy, modify, merge, publish, distribute, sublicense, and/or sell
;   copies of the Software, and to permit persons to whom the Software is
;   furnished to do so, subject to the following conditions:
;
;   The above copyright notice and this permission notice shall be included in all
;   copies or substantial portions of the Software.
;
;   THE SOFTWARE IS PROVIDED "AS IS", WITHOUT WARRANTY OF ANY KIND, EXPRESS OR
;   IMPLIED, INCLUDING BUT NOT LIMITED TO THE WARRANTIES OF MERCHANTABILITY,
;   FITNESS FOR A PARTICULAR PURPOSE AND NONINFRINGEMENT. IN NO EVENT SHALL THE
;   AUTHORS OR COPYRIGHT HOLDERS BE LIABLE FOR ANY CLAIM, DAMAGES OR OTHER
;   LIABILITY, WHETHER IN AN ACTION OF CONTRACT, TORT OR OTHERWISE, ARISING FROM,
;   OUT OF OR IN CONNECTION WITH THE SOFTWARE OR THE USE OR OTHER DEALINGS IN THE
;   SOFTWARE.
;==============================================================================
;   Filename:               univ_3-7-0-0.asm
;   Associated diagram:     univ_3-7-0-x.sch
;   Author:                 Jacek Siwilo
;   Note:                   AC motor blind controller
;==============================================================================
;   Revision History
;   Rev:  Date:     Details:
;   0     04.2014   Original version
;   1     10.2015   Updated with "univ3-routines-rev4.inc"
;   2     11.2022   Updated with "univ3-routines-rev9.inc"
;==============================================================================
;===  FIRMWARE DEFINITIONS  =================================================== 
;==============================================================================
    #define    ATYPE    .7                            ;application type [0-255]
    #define    AVERS    .0                         ;application version [0-255]
    #define    FVERS    .0                            ;firmware version [0-255]

    #define    FREV     .2                         ;firmware revision [0-65536]
;==============================================================================
;===  NEEDED FILES  ===========================================================
;==============================================================================
    LIST P=18F26K80                              ;directive to define processor
    #include <P18F26K80.INC>           ;processor specific variable definitions
    #include "univ_3-7-0-0-rev2.inc"                         ;project variables
INCLUDEDFILES   code  
    #include "univ3-routines-rev9.inc"                     ;UNIV 3 CPU routines

;==============================================================================
;===  FIRMWARE CHECKSUM  ======================================================
;==============================================================================
FIRMCHKSM   code    0x001000
    DB      0x63, 0xD6, 0xA4, 0xFF, 0xFF, 0xFF, 0xFF, 0xFF
;==============================================================================
;===  FIRMWARE ID  ============================================================
;==============================================================================
FIRMID      code    0x001010
    DB      0x30, 0x00, 0x03,ATYPE,AVERS,FVERS,FREV>>8,FREV
;            |     |     |     |     |     |     |_____|_____ firmware revision
;            |     |     |     |     |     |__________________ firmware version
;            |     |     |     |     |_____________________ application version
;            |     |     |     |______________________________ application type
;            |     |     |________________________________ hardware version '3'
;            |_____|______________________________________ hardware type 'UNIV'
;==============================================================================
;===  MOVED VECTORS  ==========================================================
;==============================================================================
;PROGRAM RESET VECTOR
FIRMRESET   code    0x1020
        goto    Main
;PROGRAM HIGH PRIORITY INTERRUPT VECTOR
FIRMHIGHINT code    0x1030
        call    HighInterrupt
        retfie
;PROGRAM LOW PRIORITY INTERRUPT VECTOR
FIRMLOWINT  code    0x1040
        call    LowInterrupt
        retfie

;==============================================================================
;===  FIRMWARE STARTS  ========================================================
;==============================================================================
FIRMSTART   code    0x001050
;------------------------------------------------------------------------------
;---  LOW PRIORITY INTERRUPT  -------------------------------------------------
;------------------------------------------------------------------------------
LowInterrupt
        movff   STATUS,STATUS_LOW           ;save STATUS register
        movff   WREG,WREG_LOW               ;save working register
        movff   BSR,BSR_LOW                 ;save BSR register
        movff   FSR0L,FSR0L_LOW             ;save other registers used in high int
        movff   FSR0H,FSR0H_LOW
        movff   FSR1L,FSR1L_LOW
        movff   FSR1H,FSR1H_LOW

    ;main firmware ready flag
        banksel FIRMREADY
        btfss   FIRMREADY,0
        bra     ExitLowInterrupt            ;main firmware is not ready yet
    ;CAN buffer
        banksel CANFULL
        btfsc   CANFULL,0                   ;check if CAN received anything
        call    CANInterrupt                ;proceed with CAN interrupt

ExitLowInterrupt
        movff   BSR_LOW,BSR                 ;restore BSR register
        movff   WREG_LOW,WREG               ;restore working register
        movff   STATUS_LOW,STATUS           ;restore STATUS register
        movff   FSR0L_LOW,FSR0L             ;restore other registers used in high int
        movff   FSR0H_LOW,FSR0H
        movff   FSR1L_LOW,FSR1L
        movff   FSR1H_LOW,FSR1H
    return
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

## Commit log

2014-04-28 hardware revision 1
    [pcb_univ_3-2-(1-2)-x-rev1.brd, pcb_univ_3-2-(1-2)-x-rev1.sch, univ_3-7-0-x-rev1.sch]
2014-04-28 firmware UNIV 3.7.0.0-rev0
    [univ_3-7-0-0-rev0-memory.xlsx]
2015-11-08 firmware UNIV 3.7.0.0 revision 1
    [univ_3-7-0-0-rev1-memory.xlsx]
2015-12-13 hardware UNIV 3.7.0.x rev1
    [pcb_univ_3-2-(1-2)-x-rev1.brd, pcb_univ_3-2-(1-2)-x-rev1.sch, univ_3-7-0-x-rev1.sch]
2015-12-13 hardware UNIV 3.7.0.x revision 1
    [pcb_univ_3-2-(1-2)-x-rev1.brd, pcb_univ_3-2-(1-2)-x-rev1.sch, univ_3-7-0-x-rev1.sch]
2015-12-13 hardware UNIV 3.7.0.x revision 3
    [pcb_univ_3-(2-7)-(5-0)-x-rev3.brd, pcb_univ_3-(2-7)-(5-0)-x-rev3.sch, univ_3-7-0-x-rev3.sch]
2017-03-05 hardware UNIV 3.7.0.x revision 4
    [pcb_univ_3-(2-7)-(5-0)-x-rev4.brd, pcb_univ_3-(2-7)-(5-0)-x-rev4.sch, univ_3-7-0-x-rev4.sch]
2022-11-05 firmware UNIV 3.7.0.0 revision 2
    [univ_3-7-0-0-rev2-memory.xlsx]
2024-06-25 hardware UNIV 3.7.0.x revision 4 gerber

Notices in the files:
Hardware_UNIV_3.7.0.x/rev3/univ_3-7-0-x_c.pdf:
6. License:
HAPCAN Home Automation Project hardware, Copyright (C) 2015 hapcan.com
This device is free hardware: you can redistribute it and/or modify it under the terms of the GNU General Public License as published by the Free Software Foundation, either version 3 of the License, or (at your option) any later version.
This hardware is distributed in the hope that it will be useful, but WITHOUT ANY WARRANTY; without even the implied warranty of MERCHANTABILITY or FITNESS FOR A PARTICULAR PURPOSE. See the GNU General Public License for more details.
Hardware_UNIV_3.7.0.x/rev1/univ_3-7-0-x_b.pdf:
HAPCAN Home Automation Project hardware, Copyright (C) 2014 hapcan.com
